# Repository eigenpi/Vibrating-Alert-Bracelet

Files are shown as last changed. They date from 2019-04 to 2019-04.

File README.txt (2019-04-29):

April 29 2019

This repository contains all the design files for the E45 project "Vibration Alert Bracelet (VAB)".
The bracelet design has two basic functions: 
1) Receive a wireless signal from a main control center and respond with a vibration to alert the person wearing the bracelet about emergencies, and 
2) Generate an emergency signal by pressing a button that is sent from the bracelet to the control center. 

Students who worked on this project:
Kelsey Conley, Alex Foyer, Patrick Hara, Tom Janik, Jason Reichard, Jon D’Souza
Dept. of Electrical and Computer Engineering 
Marquette University 
Fall'18-Spring'19

Adviser:
Cris Ababei  

Project home: 
http://dejazzer.com/hardware.html (Project “Vibrating Alert Bracelet”)

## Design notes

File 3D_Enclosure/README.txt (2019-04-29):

Top3.prt and bottom3.prt are the same as the stl files named Senior_Design_Top_Final_Rev
 and Senior_Design_Bottom_Final_Rev. The assembly part contains both the top, bottom, board 
and battery in an assembly. The board2.0 part is the 3d mock up of the board with major
components and to the exact measured size of the pcb.
Program used to create parts was NX 8.5

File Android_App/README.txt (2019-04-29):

The project was created in Android Studio v3.2

To compile and run the app, I'd recommend importing the project into Android Studio using 
the build.gradle file included in the zip. After downloading the project, extract it and 
save it to its own directory. Then, inside Android Studio, select the option to import
a project, then locate the build.gradle file located in the top level of the now unzipped
project directory. The project should then be able to be run on an android device connected
to the computer (you will have to turn on usb debugging on the phone).

Once the project is created and compiled, the device will need to be connected to the 
wifi network created by the server. This is a temporary solution since the bracelet 
and app are not currently able to find the server unless it's connected to the specific
network.

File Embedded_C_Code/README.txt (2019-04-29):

This project was created using the Arduino IDE

This .ino file contains the code necessary for the functonality of the bracelet. This program requires the BraceletHardware.h header file in order to compile. There are also two additional libraries that need to be added for the operation. The first is the ESP8266 library version 2.4.0-rc2 in order for the light sleep mode to function. The next necessary library is Streaming which is necessary for the header file.

Once the file is opened a few changes need to be made for the code to function depending on the setup. The ssid, password, and host IP address need to be changed to match your current system. Once these changes have been made the board must be changed by going to Tools>Board and then you can select either generic ESP8266 module or Adafruit HUZZAH ESP8266. If one does not compile try the other.

Serial monitoring is enabled by default but can be turned off by adding the arguement of 1 to hwInit() call in the setup.

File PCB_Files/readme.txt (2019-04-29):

PCB Files
ReadMe by Jason Reichard
Team E45 - Marquette University
April 27, 2019

This folder contains all of the files required to reconstruct the final PCB design of the VAB:

	PCB_TOP_REV2.png - Board layout top side screenshot from EasyEDA

	PCB_BOT_REV2.png - Board layout bottom side screenshot from EasyEDA

	Rev2 Schematic.png - Schematic screenshot from EasyEDA

	Rev2 Schematic.json - Schematic design file that can be opened with EasyEDA and modified

	Rev2 Layout.json - PCB design file that can be opened with EasyEDA and modified

	Rev2 Gerbers.zip - contains all of the gerber files necessary for manufacturing the PCB
	
	Rev2 PCB BOM.xlsx - Bill of materials for assembly of the PCB

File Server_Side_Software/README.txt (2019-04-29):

To compile and run the server, download the python code and client list and store them to the same directory on 
the device. The device running the server must have python3 installed and be able to function as a wifi access 
point. 

At the moment, all devices must be connected to the network created by the server device to allow for the system 
to function as intended. After setting up the device, the server serial output will display the connections received.

To change the displayed list of clients, the clientList.txt file must be modified and the server needs to be
restarted. In order for the server to recognize the bracelets, the MAC address for the bracelet will need to be known
and inputted. Once the server is restarted, the server will report the newly updated list of clients to any connected apps.

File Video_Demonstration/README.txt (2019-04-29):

April 27 2019

This is a short video presentation of the Senior Design Project (SDP) E45.
Dept. of Electrical and Computer Engineering, Marquette University, Fall'18-Spring'19. 
Final report and  complete design source files can be found at: 
http://dejazzer.com/hardware.html (Project “Vibrating Alert Bracelet”) 

Your video will be live at: https://youtu.be/Zs1TMDEWUGM

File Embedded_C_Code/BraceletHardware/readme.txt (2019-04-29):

BraceletHardware.h
ReadMe by Jason Reichard
Team E45 - Marquette University
April 26, 2019

This header file is created to provide easy access to the Vibrating Alert Bracelet's Hardware. The function bodies are included in the header to 
provide full visibility. 

It provides two classes:
	A Battery class to manage the current state of the battery, the battery charger, and the state of the bi-color LED 
	in response to battery charge level.

		To use the battery simply initialize a new Battery object with the default constructor. The state of the battery will be updated 
		upon calling Battery.update(). The state of the battery charger & charge-dependent LED lighting will be updated upon calling
		Battery.charge(). Note that Battery.charge() also calls Battery.update().

	A BraceletWifi class to manage the wifi connection of the bracelet. This class was built simply as a convenience to connect and reconnect
	to a WiFi network as quickly as possible when used in conjunction with light sleep.

		To use the wifi class initialize a new BraceletWifi object with your SSID and password.

		Calling BraceletWifi.connect() will attempt to connect to the WiFi network as fast as possible. After connecting to the network for the
		first time the configuration settings of the network are remembered to facilitate a much faster reconnection awterward.

It also provides pin definitions, a hardware initialization function, and several other utility functions including a working timed Light Sleep 
implementation.

As of 4/26/2019 the only way to make light sleep work is to be using the ESP8266 core version 2.4.0-rc1 or 2.4.0-rc2.

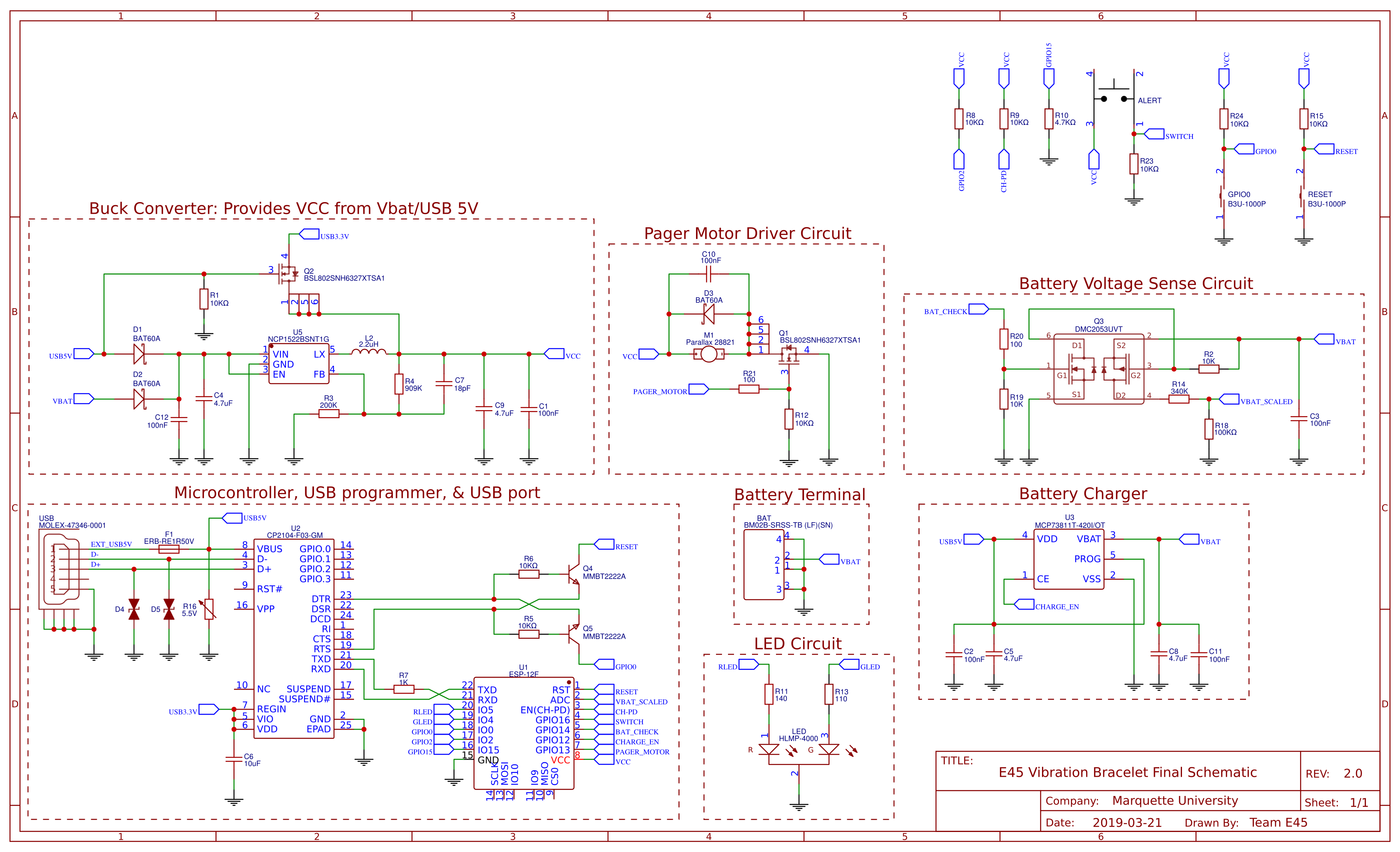
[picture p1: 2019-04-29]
PCB_Files/Rev2 Schematic.png

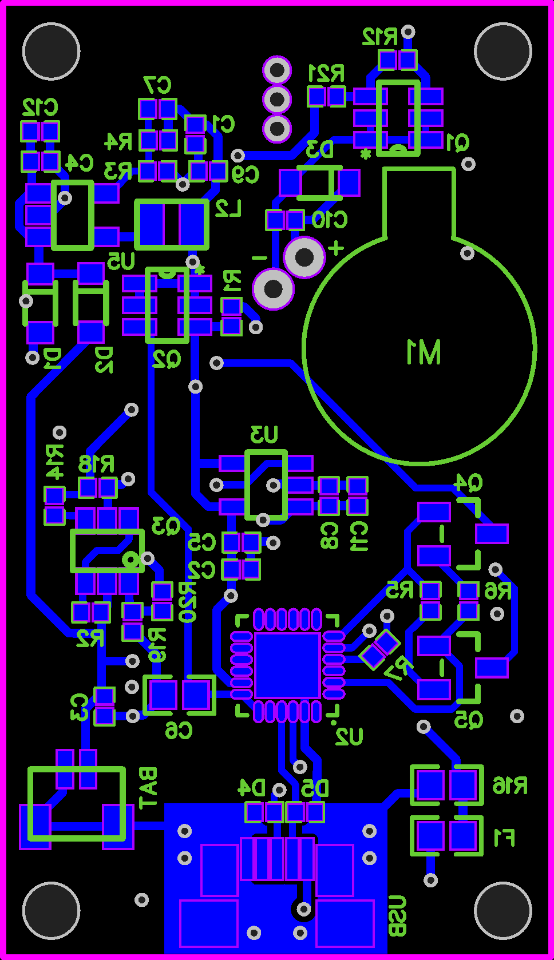
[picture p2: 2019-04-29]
PCB_Files/PCB_BOT_REV2.png

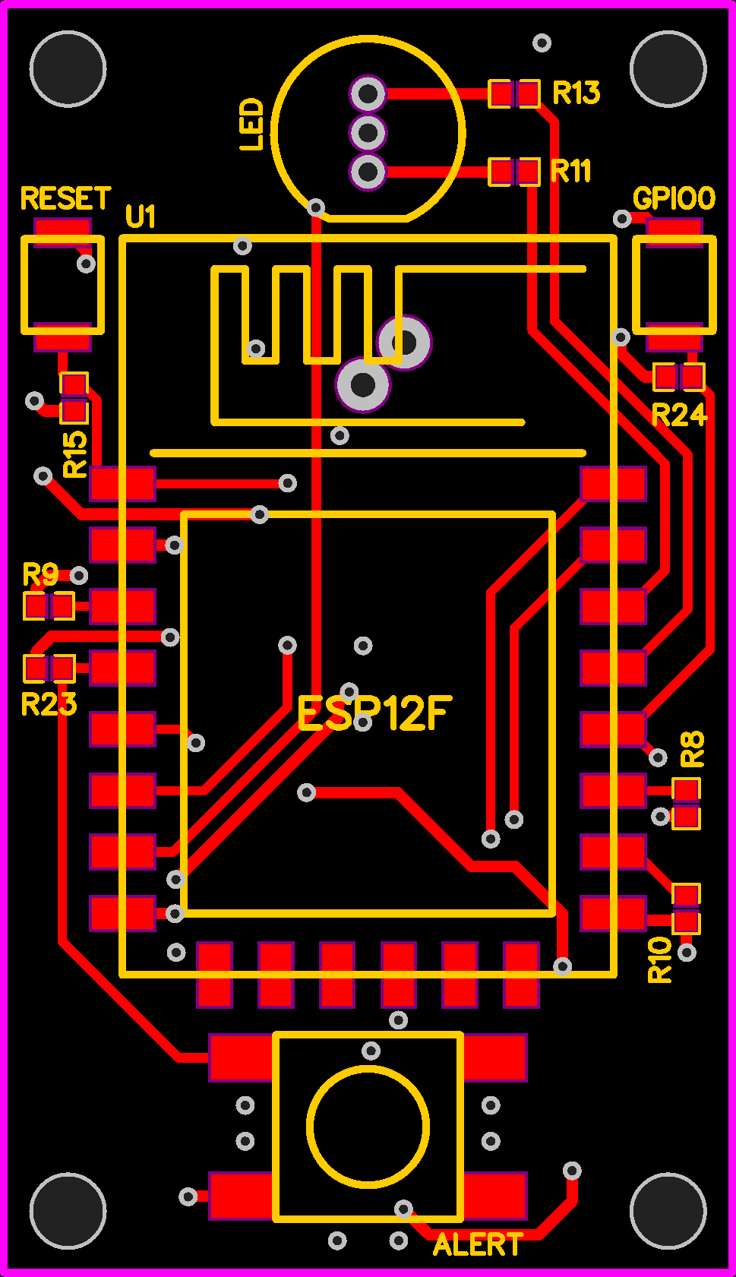
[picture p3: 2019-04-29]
PCB_Files/PCB_TOP_REV2.png

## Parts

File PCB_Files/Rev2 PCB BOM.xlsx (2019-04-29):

Name | Designator | Part Number | Manufacturer | Quantity | Price Each (USD) | Price Per Assy. (USD) | Footprint | Supplier
PCB | PCB | - | JLCPCB | 1 | $10.00 | $10.00 | - | JLCPCB
Battery | Battery | ASR00007 | TinyCircuits | 1 | $5.95 | $5.95 | - | DigiKey (https://www.digikey.com/product-detail/en/tinycircuits/ASR00007/1832-1032-ND/7404517)
12/250V 0402' TVS | D4,D5 | PGB1010402KR | Littelfuse | 2 | $0.66 | $1.32 | 0402' | Mouser (https://www.mouser.com/ProductDetail/Littelfuse/PGB1010402KR)
4.7uF 0402' Capacitor | C9,C4,C5,C8 | C1005X5R1A475K050BC | TDK | 4 | $0.62 | $2.48 | 0402' | Mouser (https://www.mouser.com/ProductDetail/TDK/C1005X5R1A475K050BC)
100KΩ 0402' Resistor | R18 | ESR01MZPF1003 | ROHM Semiconductor | 1 | $0.28 | $0.28 | 0402' | Mouser (https://www.mouser.com/ProductDetail/ROHM-Semiconductor/ESR01MZPF1003?qs=493kPxzlxfJmWK%252BwDG8qPw%3D%3D)
18pF 0402' Capacitor | C7 | C0402C180J5HACTU | KEMET | 1 | $0.11 | $0.11 | 0402' | Mouser (https://www.mouser.com/ProductDetail/KEMET/C0402C180J5HACTU?qs=W0yvOO0ixfFfe6RYJJhFUg%3D%3D)
10KΩ 0402' Resistor | R5,R6,R8,R9,R12,R15,R23,R24,R1,R2,R19 | SFR01MZPF1002 | ROHM Semiconductor | 11 | $0.10 | $1.10 | 0402' | Mouser (https://www.mouser.com/ProductDetail/ROHM-Semiconductor/SFR01MZPF1002)
100nF 0402' Capacitor | C10,C3,C1,C2,C11,C12 | 0402YC104KAT2A | AVX | 6 | $0.10 | $0.60 | 0402' | Mouser (https://www.mouser.com/ProductDetail/AVX/0402YC104KAT2A)
100Ω 0402' Capacitor | R20,R21 | CRGP0402F100R | TE Connectivity | 2 | $0.10 | $0.20 | 0402' | Mouser (https://www.mouser.com/ProductDetail/TE-Connectivity-Holsworthy/CRGP0402F100R)
140Ω 0402' Resistor | R11 | ERJ-2RKF1400X | Panasonic | 1 | $0.10 | $0.10 | 0402' | Mouser (https://www.mouser.com/ProductDetail/Panasonic/ERJ-2RKF1400X)
110Ω 0402' Resistor | R13 | ERJ-2RKF1100X | Panasonic | 1 | $0.10 | $0.10 | 0402' | Mouser (https://www.mouser.com/ProductDetail/Panasonic/ERJ-2RKF1100X?qs=sGAEpiMZZMvdGkrng054t8Pyfa06IR6dX2v52MHbRv4%3D)
200KΩ 0402' Resistor | R3 | SFR01MZPF2003 | ROHM Semiconductor | 1 | $0.10 | $0.10 | 0402' | Mouser (https://www.mouser.com/ProductDetail/ROHM-Semiconductor/SFR01MZPF2003)
1KΩ 0402' Resistor | R7 | SFR01MZPF1001 | ROHM Semiconductor | 1 | $0.10 | $0.10 | 0402' | Mouser (https://www.mouser.com/ProductDetail/ROHM-Semiconductor/SFR01MZPF1001)
4.7KΩ 0402' Resistor | R10 | SFR01MZPF4701 | ROHM Semiconductor | 1 | $0.10 | $0.10 | 0402' | Mouser (https://www.mouser.com/ProductDetail/ROHM-Semiconductor/SFR01MZPF4701?qs=byeeYqUIh0MAuF3G7P9Qrg%3D%3D)
909KΩ 0402' Resistor | R4 | AC0402FR-07909K | YAEGO | 1 | $0.10 | $0.10 | 0402' | Mouser (https://www.mouser.com/ProductDetail/Yageo/AC0402FR-07909KL)
340KΩ 0402' Resistor | R14 | RC0402FR-07340KL | YAEGO | 1 | $0.10 | $0.10 | 0402' | Mouser (https://www.mouser.com/ProductDetail/Yageo/RC0402FR-07340KL)
5.5V 0603' Varistor | R16 | V5.5MLA0603LNR | Littlefuse | 1 | $0.68 | $0.68 | 0603' | Mouser (https://www.mouser.com/ProductDetail/Littelfuse/V55MLA0603LNR)
10uF 0603' Capacitor | C6 | EMK107BBJ106MA-T | TAIYO YUDEN | 1 | $0.35 | $0.35 | 0603' | Mouser (https://www.mouser.com/ProductDetail/Taiyo-Yuden/EMK107BBJ106MA-T)
1.5A 0603' Fuse | F1 | ERB-RE1R50V | Panasonic | 1 | $0.32 | $0.32 | 0603' | Mouser (https://www.mouser.com/ProductDetail/Panasonic/ERB-RE1R50V)
2.5 x 3 x 1.2mm SMD Switch | RESET,GPIO0 | B3U-1000P | Omron Electronics | 2 | $0.97 | $1.94 | B3U-1000PM | Mouser (https://www.mouser.com/ProductDetail/Omron-Electronics/B3U-1000P)
2-Pos Micro JST Header | BAT | BM02B-SRSS-TB (LF)(SN) | JST Sales America | 1 | $0.69 | $0.69 | BM02B-SRSS-TB (LF)(SN) | DigiKey (https://www.digikey.com/product-detail/en/BM02B-SRSS-TBT(LF)(SN)/455-2955-1-ND/5725846/?itemSeq=285362252)
ESP8266 Module | U1 | ESP-12F | Ai-Thinker | 1 | $2.95 | $2.95 | ESP-12F(ESP8266MOD) | Amazon (https://www.amazon.com/gp/product/B077V4Y9VD/ref=ox_sc_mini_detail?ie=UTF8)
SMD Micro USB Header | USB | 47346-0001 | MOLEX | 1 | $0.89 | $0.89 | MOLEX-47364-0001 | Mouser (https://www.mouser.com/ProductDetail/Molex/47346-0001)
6 x 6 x 4.3mm SMD Switch | ALERT | LL3301NF065QG | E-Switch | 1 | $0.65 | $0.65 | PUSHBUTTON_SMD_11.2X5.9 | Mouser (https://www.mouser.com/ProductDetail/E-Switch/LL3301NF065QG)
USB to UART IC | U2 | CP2104-F03-GM | SILICON LABS | 1 | $1.77 | $1.77 | QFN-24_4X4X05P | Mouser (https://www.mouser.com/ProductDetail/634-CP2104-F03-GM)
2.2uH SMD Inductor | L2 | VLS252015ET-2R2M | TDK | 1 | $0.54 | $0.54 | SMD-L-2.5X2.0X1.0 | Mouser (https://www.mouser.com/ProductDetail/TDK/VLS252015ET-2R2M)
3A, 10V Schottkey Diode | D3,D1,D2 | BAT 60A E6327 | Infineon | 3 | $0.45 | $1.35 | SOD-323 | Mouser (https://www.mouser.com/ProductDetail/Infineon-Technologies/BAT-60A-E6327)
Small Signal BJT | Q4,Q5 | MMBT2222AWT3G | On Semiconductor | 2 | $0.14 | $0.28 | SOT-23-3 | DigiKey (https://www.digikey.com/product-detail/en/on-semiconductor/MMBT2222AWT3G/MMBT2222AWT3GOSCT-ND/9086855)
Battery Charging IC | U3 | MCP73811T-420I/OT | MICROCHIP | 1 | $0.52 | $0.52 | SOT-23-5 | Mouser (https://www.mouser.com/ProductDetail/Microchip-Technology/MCP73811T-420I-OT)
7.5A, 20V N-Channel FET | Q2,Q1 | BSL802SNH6327XTSA1 | Infineon | 2 | $0.57 | $1.14 | SOT-23-6 | Mouser (https://www.mouser.com/ProductDetail/Infineon-Technologies/BSL802SNH6327XTSA1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)
Red/Green LED | LED | HLMP-4000 | Broadcom | 1 | $0.68 | $0.68 | T1 5mm | Mouser (https://www.mouser.com/ProductDetail/Broadcom-Avago/HLMP-4000)
Buck Converter IC | U5 | NCP1522BSNT1G | ON Semiconductor | 1 | $0.79 | $0.79 | TSOP-5 | Mouser (https://www.mouser.com/ProductDetail/863-NCP1522BSNT1G)
4.6/3.2A, 20V FET Pair | Q3 | DMC2053UVT-7 | Diodes Incorporated | 1 | $0.41 | $0.41 | TSOT6 | Mouser (https://www.mouser.com/ProductDetail/Diodes-Incorporated/DMC2053UVT-7)
90mA, 3V Pager Motor | M1 | 28821 | Parallax | 1 | $4.50 | $4.50 | VIBE-MOTOR-10MM | DigiKey (https://www.digikey.com/product-detail/en/parallax-inc/28821/28821-ND/3083191)
 |  |  |  |  | Total Assy. Cost: | $43.19

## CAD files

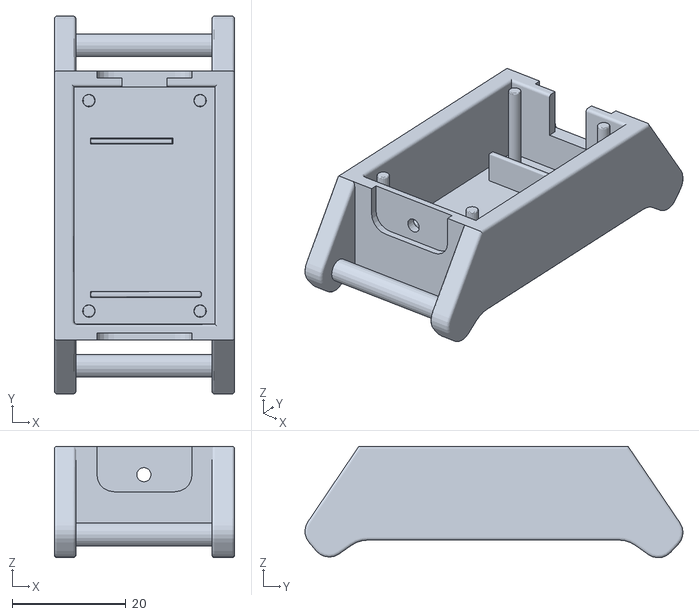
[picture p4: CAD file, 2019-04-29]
3D_Enclosure/Senior_Design_Bottom_Final_Rev.stl
31.7 x 66.5 x 19.6

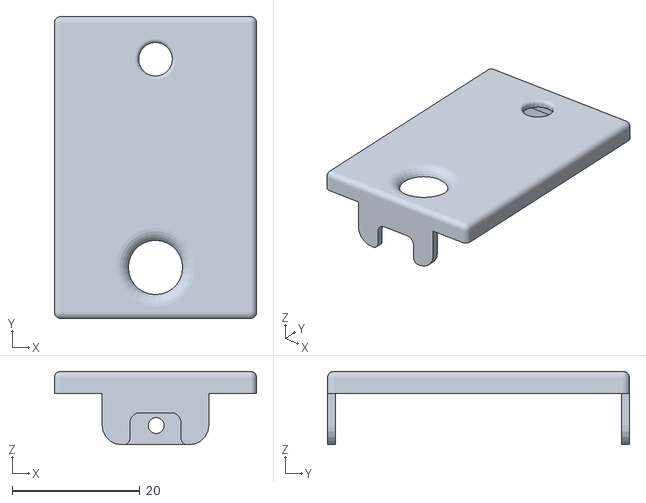
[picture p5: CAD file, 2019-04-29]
3D_Enclosure/Senior_Design_Top_Final_Rev.stl
31.7 x 47.3 x 11.5

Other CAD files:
3D_Enclosure/assembly.prt
3D_Enclosure/board2.0.prt
3D_Enclosure/bottom 3.prt
3D_Enclosure/top3.prt

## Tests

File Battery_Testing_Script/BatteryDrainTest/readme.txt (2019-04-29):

BatteryDrainTest.ino
ReadMe by Jason Reichard
Team E45 - Marquette University
April 26, 2019

This program is used to test the lifespan of a single battery charge by having the VAB upload the battery voltage & the
current value of millis() to a google sheet. The program runs until the battery is completely drained. millis() is used to detect whether
or not the bracelet has reset itself during the test. The program also features the ability to recharge the battery when plugged into USB power.

To use this program you must do the following:
	
	Create a google sheet

	go to tools -> script editor

	Paste the code below:

		function doGet(e) {
		var mo = e.parameter.func;
			if(mo == "addData") {
				var stat = add_data(e);
				if(stat == 1) {
					var result = {status : true};
					return ContentService.createTextOutput(JSON.stringify(result)).setMimeType(ContentService.MimeType.JSON);
				}
			}
		}

		function add_data(e) {
			var sheet = SpreadsheetApp.openByUrl('YourGoogleSheetURLHere');
  
			var CurrentDate = new Date();
			var Date_ = Utilities.formatDate(CurrentDate, "GMT-05:00", "MM/dd/YYYY");
			var Time_ = Utilities.formatDate(CurrentDate, "GMT-05:00", "HH:mm:ss");

			sheet.appendRow([Date_, Time_, e.parameter.millis, e.parameter.batV]);
			return 1;
		}

	Replace the Google sheet URL with your own & edit the date & time formats as you see fit

	Click Publish -> Deploy as a web app

	Copy the text in the web app URL between "https://script.google.com/macros/s/" and "/exec" This is your ScriptID

	Paste your ScriptID into the program

	Edit the SSID & password to match those of your WiFi network

	Save, compile, & upload to the ESP8266

	Data will start appearing in your google sheet if everything was done correctly.

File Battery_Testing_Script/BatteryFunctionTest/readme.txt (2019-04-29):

BatteryFunctionTest.ino
ReadMe by Jason Reichard
Team E45 - Marquette University
April 26, 2019

This is a short test progam whose sole purpose was to refine the functionality of the Battery class found in BraceletHardware.h 

The testing was necessary in order to ensure that the detection of USB power was reliable. Due to the lack of GPIO pins, the detection of USB 
power is done via reading the battery voltage, enabling the charger, and reading it again. A comparison is then done on the result of the two
measurements in order to determine whether the bracelet is plugged in.

The program will continuously print data about the current state of the battery:
	
	Battery Voltage

	Charger Voltage

	State of Charge

	Plugged-In flag

	Charged flag
	
	Low Battery Warning flag

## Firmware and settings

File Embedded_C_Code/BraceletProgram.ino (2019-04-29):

#include <Streaming.h>
#include <ESP8266WiFi.h>
#include <Ticker.h>
#include "BraceletHardware.h"
// Information for connecting to the network
char* ssid = "E45";
char* password = "ihavefallenandicantgetup";
// IP address for the server
const char* host = "192.168.42.1";
// Creating necessary variables for the program
bool connection = false;
Ticker vibrate;
double batV;
long runtime;
String alert;
int count = 0;
Battery myBattery;
braceletWifi myWifi(ssid, password, 1);
// Method for vibrating the motor when an alert is received
void vibrateMotor() {
  int state = digitalRead(PAGER_MOTOR);  
  digitalWrite(PAGER_MOTOR, !state); 
  count++;
  if(count==10) {
    digitalWrite(PAGER_MOTOR, LOW);
    count = 0;
    vibrate.detach();
  }
}

void setup()
{
  // Intitialize all the pins and enable serial monitoring
  hwInit();
}


void loop()
{
  // Connect to the network and update battery information
  myWifi.connect();
  Serial.println("Connected to the Wifi");
  myBattery.charge();
  // Start Wifi client that will communicate with the server
  WiFiClient client;
  Serial.printf("\n[Connecting to %s ... ", host);
  // Connect to the server using the IP address of the server
  if ((client.connect(host, 43000)))
  {
    Serial.println("connected]");
    connection = true;
    Serial.println("[Sending a request]");
    // Identify the device as a bracelet
    client.print("esp");
    // Receives and prints response from the server
    Serial.println("[Response:]");
    String response = client.readString();
    Serial.println(response);
    // The ESP creates a str that contains information on whether the button has been pressed
    char str[10];
    strcpy(str, "CHECK IN:");
    if(buttonPressed){
      strcat(str, "1");
      // The LED will blink red when an alert is being sent
      digitalWrite(RLED, HIGH);
      delay(500);
      digitalWrite(RLED, LOW);
      buttonPressed = false;
    }
    // If no alert is given a 0 is sent to the server
    else {
      strcat(str, "0");
    }
    // The adjusted string is then sent to the server
    client.print(str);
    Serial.println(str);
    // The MacAddress is sent to identify the bracelet
    client.print(WiFi.macAddress());
    // The ESP receives a message that tells if the server sent out an alert
    alert = client.readString();
    Serial.println(alert);
    // If an alert is received the bracelet will vibrate
    if(alert == "ALERT") {
      vibrate.attach(0.5, vibrateMotor); 
    }
    // The bracelet then disconnects from the server
    client.stop();
    Serial.println("\n[Disconnected]");
  }
  // If the bracelet cannot connect to the server the client is closes
  else
  {
    Serial.println("connection failed!]");
    client.stop();
  }
  // If the bracelet is plugged in then there is no need for sleep
  if(myBattery.pluggedIn){
    if(digitalRead(BUTTON)){
      buttonPressed=true;
    }
  }
//  // Once everything has completed the bracelet will sleep 
  else {
    lightSleep(30000);
  }
 

}

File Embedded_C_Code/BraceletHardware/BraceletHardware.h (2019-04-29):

#pragma once

/*
	Name:       BraceletHardware.h
	Created:	4/8/2019
	Author:     Jason Reichard
*/

#include <ESP8266WiFi.h>
#include <Streaming.h>

extern "C" {
	#include "user_interface.h"
}

// Button state
bool buttonPressed = false;

// Pin definitions
const int RLED = 5;
const int GLED = 4;
const int PAGER_MOTOR = 13;
const int BUTTON = 16;
const int BAT_CHECK = 14;
const int CHARGE_EN = 12;
const int VBAT_SCALED = A0;

// hardware setup stuff
void hwInit(boolean serialDisable = 0) {
	if (serialDisable) {
		Serial.end();
	} else {
		Serial.begin(115200);
	}

	// configure GPIO pins
	pinMode(RLED, OUTPUT);
	pinMode(GLED, OUTPUT);
	pinMode(PAGER_MOTOR, OUTPUT);
	pinMode(BUTTON, INPUT);
	pinMode(BAT_CHECK, OUTPUT);
	pinMode(VBAT_SCALED, INPUT);
	pinMode(CHARGE_EN, OUTPUT);

	// sets up our output pins to be in the correct state upon startup because the ESP is dumb and likes to set some pins high upon boot for reasons beyond me
	digitalWrite(CHARGE_EN, 0);
	digitalWrite(BAT_CHECK, 0);
	digitalWrite(RLED, 0);
	digitalWrite(GLED, 0);
	digitalWrite(PAGER_MOTOR, 0);
}

// map function, but with doubles
double mapd(double x, double in_min, double in_max, double out_min, double out_max) {
	return (x - in_min) * (out_max - out_min) / (in_max - in_min) + out_min;
}

// returns the battery voltage when passed an adc reading (0 - 1023)
double adcToVolts(double adcReading) {
	return (adcReading / 1024.0)*4.27;
}

// colors the LED from red to green (0 = red, 255 = green, 128 = yellow/orange)
// values greater than 255 default to 255
// values less than 0 default to 0
void ledGradient(int n) {
	int level = n;
	if (n > 255) {
		level = 255;
	}
	if (n < 0) {
		level = 0;
	}
	analogWrite(RLED, 255 - level);
	analogWrite(GLED, level);
}

// turns both LEDs off
void LEDOff() {
	digitalWrite(RLED, 0);
	digitalWrite(GLED, 0);
}

// sleep wakeup callback
// it's a hack, don't ask me how it works
void callback() {
	Serial << "z" << endl;
	Serial.flush();
}

// light sleep for desired duration in milliseconds
void sleepCycle(int ms) {
	wifi_set_opmode(NULL_MODE);
	wifi_fpm_set_sleep_type(LIGHT_SLEEP_T);
	wifi_fpm_open();
	wifi_fpm_set_wakeup_cb(callback);
	wifi_fpm_do_sleep(ms * 5000);
	delay(ms + 1);
}

// forces the ESP into Light Sleep for the desired duration in milliseconds
void lightSleep(int ms) {
	//break the sleep up into smaller 5 second cycles
	for (int i = ms; i > 0; i -= 5000) {
		if (i > 5000) {
			// sleep for 1 second
			sleepCycle(5000);
			if(digitalRead(BUTTON)){
				buttonPressed=true;
			}
		} else {
			// sleep for remaining time
			sleepCycle(i);
		}
	}
}

// Battery class for doing battery things
class Battery {
public:
	// Battery charge state stuff
	boolean charged, pluggedIn, batLow;
	double batVoltage, chargeVoltage, chargePercent;

	// constructor
	Battery() {
		this->charged = 0;
		this->pluggedIn = 0;
		this->batLow = 0;
		this->batVoltage = 0;
		this->chargeVoltage = 0;
	}

	// charges the battery if conditions are right for it
	// Turns on the LED if plugged in:
	//		gradient from red to green depending on charge
	//		flashes green when fully charged
	void charge() {
		this->update();
		if (this->pluggedIn) {

			if (this->charged) { // plugged in & charged
				digitalWrite(CHARGE_EN, 1);
				digitalWrite(GLED, 1);
				delay(10);
				LEDOff();

			} else { // plugged in & not charged
				digitalWrite(CHARGE_EN, 1);
				ledGradient(mapd(this->batVoltage, 3.0, 4.16, 0, 255));
			}

		} else {

			// disable charging & turn off LEDs when unplugged
			if (this->charged) { // unplugged & charged
				digitalWrite(CHARGE_EN, 0);
				LEDOff();

			} else { // unplugged & not charged
				digitalWrite(CHARGE_EN, 0);
				LEDOff();
			}

			// lights the red LED if the battery is dying
			if (this->batLow) {
				ledGradient(0);
			}
		}
	}

	//updates charge percentage, battery voltage, charge voltage, charged, plugged-in, & low battery flags
	void update() {

		double bat1 = getBatV(1);
		double bat2 = getChargeV(1);

		// calculates battery charge percent (only relevant when plugged in)
		this->chargePercent = (bat1 - 1016 / 1.4) / (1016 - 1016 / 1.4);

		// detects if the battery is dying (vbat drops below 3.6v) & updates low battery warning flag
		if (bat1 < 863) {
			this->batLow = 1;
		}

		// detects if we're plugged in to USB power & updates the flag
		if ((bat2 >= 995.0) || (this->chargeVoltage >= 1.01*this->batVoltage)) {
			this->pluggedIn = 1;
		} else {
			this->pluggedIn = 0;
		}

		// updates the charged status flag if we're plugged in
		if (this->pluggedIn) {
			if (this->chargePercent >= 0.99) {
				this->charged = 1;
			}
			if (this->chargePercent <= 0.95) {
				this->charged = 0;
			}
		}
	}
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
